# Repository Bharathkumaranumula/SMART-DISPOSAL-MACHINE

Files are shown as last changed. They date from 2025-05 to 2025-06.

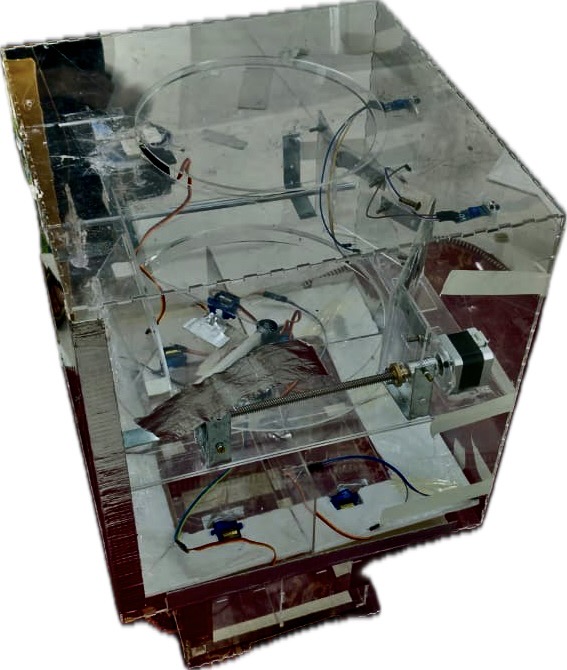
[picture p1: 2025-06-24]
sdm2.jpeg

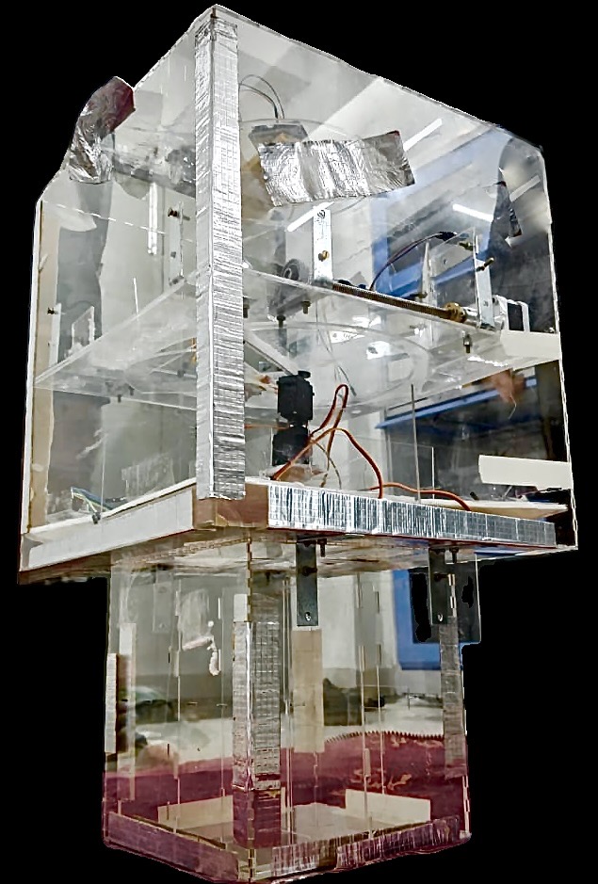
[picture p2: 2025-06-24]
Subject.jpeg

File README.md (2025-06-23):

♻️ Smart Disposal Machine - Green Guardian

Welcome to the repository of Green Guardian, a Smart Disposal Machine built to modernize and automate waste management. Designed with a combination of AI, IoT, and mechanical engineering tools this system aims to reduce human intervention, improve hygiene, and enable intelligent waste segregation.

🚀 Project Overview

The Smart Disposal Machine (SDM) is an innovative solution for waste handling that automatically:

-->Detects waste using a USB camera

-->Classifies it using AI (Gemini 1.5)

-->Compresses it with a lead screw mechanism.

-->Sorts it into the appropriate category (biodegradable, recyclable, or non-recyclable).

-->Monitors fill levels and notifies users in real-time via a web dashboard.

It is ideal for use in schools, campuses, offices, and smart cities, offering contactless interaction, increased efficiency, and scalable infrastructure for sustainable waste management.

🧠 Key Features

✅ AI-Powered Waste Classification: Utilizes Google Gemini 1.5 to categorize waste into proper compartments.

📆 Automated Compression : Reduces volume using a lead screw and NEMA17 stepper motor for extended storage capacity.

📡 IoT Monitoring : Ultrasonic sensors track bin levels in real-time and update a web dashboard (Streamlit).

🧬 Hygienic Operation : Touchless lid operation with IR sensors and servos minimizes contamination risk.

🗌 Web Dashboard : Real-time status with color indicators and bin location mapping. Includes unique bin IDs and notification alerts.

🛠️ Technical Stack

Component&                                         Description

AI Model      -----------------                                 Gemini 1.5 (Google)

Microcontrollers      --------------------                         Raspberry Pi 4, Arduino Uno

Sensors          ----------------------                              Ultrasonic, IR Proximity

Motors           ----------------------                              SG90 Servo, MG995 Servo, NEMA17 Stepper

Mechanism           ---------------------                            Lead Screw Compression + Flap-based Redirection

Software             -------------------------                          Python, Streamlit Dashboard

Communication            -----------------------                      USB Camera, IoT-based Monitoring

🔮 Future Enhancements

-->Integration with smart city waste routing systems.

-->Detection of hazardous and electronic waste.

-->Full automation of waste pickup via robotics.

-->More efficient deep-learning classification models.

🤝 Contributions
We welcome contributions from developers, engineers, and researchers. Feel free to fork the repo, open issues, or submit pull requests!

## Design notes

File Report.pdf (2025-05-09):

# Smart Disposal Machine A Scientific Report on Automated Waste Compression and Segregation “GREEN GUARDIAN”

### Hostel ID- 84

### 4th February 2024

1

Technical Report | Smart Disposal Machine | IIT Guwahati

## Contents

1 Abstract | 4
2 Problem Understanding | 4
3 Mechanical Module | 5
4 Electrical Components | 7
5 Approach | 13
6 AI Model Performance Evaluation | 14
7 User Interface | 14
8 Future Scope | 16
9 Existing Smart Disposal Technologies and Comparison | 16
10 Conclusion | 17
11 References | 18

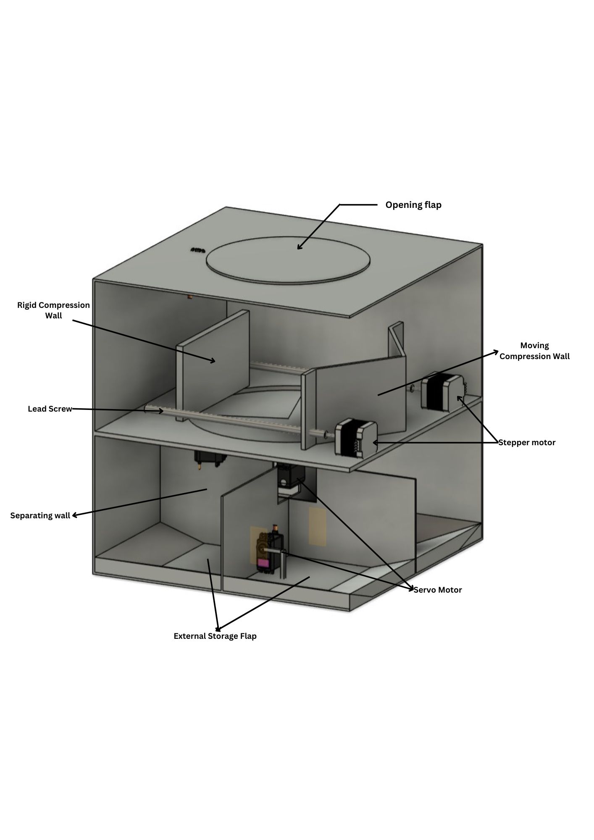
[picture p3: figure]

Figure 1:
Smart Disposal Machine

## 1 Abstract

The Smart Disposal Machine (SDM) is an advanced waste management system that incorporates AI-powered waste classification, real-time IoT monitoring, and automated mechanical segregation. This report describes the overall design of the system, focusing on the following key technologies: object detection using an SD Camera connected via USB, AI-based classification by -1.5 Pro refactor, and a lead screw-based compression mechanism to optimize waste storage and fill level monitoring via a streamlit dashboard. A mathematical model has been designed to estimate storage efficiency, waste compression, and mechanical performance. SDM considerably improves operational efficiency, sustainability, and hygiene in waste disposal at a much faster rate.

## 2 Problem Understanding

### 2.1 Challenges in Waste Management

- Inefficient Collection Schedules: Conventional dustbins require frequent manual

inspections to determine fill levels, leading to inefficiencies in waste collection.

- Overflowing Bins: High-traffic areas often experience overflowing containers,

creating unsanitary and unhygienic conditions.

- Hygiene Concerns: Maintenance staff are exposed to unsanitary conditions during

waste handling, posing health risks.

- Lack of Automation: Traditional systems lack real-time monitoring and automa-

tion, resulting in increased human intervention and operational costs.

### 2.2 Goals for the Smart Disposal Machine (SDM)

- Smart Monitoring and Notification:Use sensors to monitor fill levels in real-time

and notify personnel or automated systems when bins are full.

- Hygienic Operation: Minimize user and staff exposure to unsanitary conditions

during usage and maintenance.

- Extended Operational Time:Design the machine to extend the time between

trash retrievals using compaction or additional storage slots.

- Automation and IoT Integration:Provide remote monitoring capabilities through

a mobile app and improve automation to reduce human intervention.

- Waste Segregation:Automatically classify waste into categories such as biodegrad-

able, recyclable, and non-recyclable.

## 3 Mechanical Module

In this module in order to build the machine we have used acrylic sheets of thickness 3mm and 4mm

- Lid Mechanism: Infrared sensors are mounted onto the lid to detect motion which

would cause the lid to open or close that is facilitated by a servo motor imitating a hinge mechanism.

- Flap Mechanism: The bottom flap comprises two sections: a three-quarter circular

flap (A) and a quarter-circular flap (B) positioned beneath it.

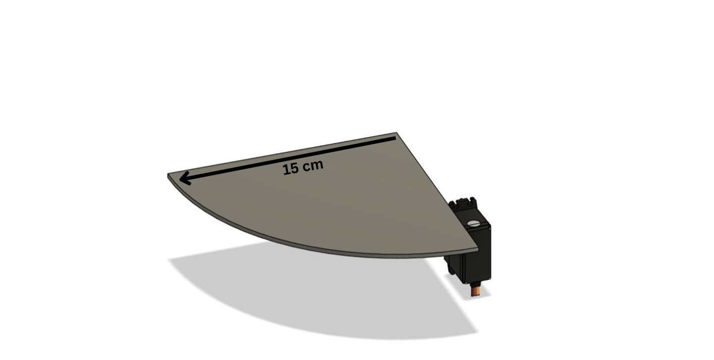
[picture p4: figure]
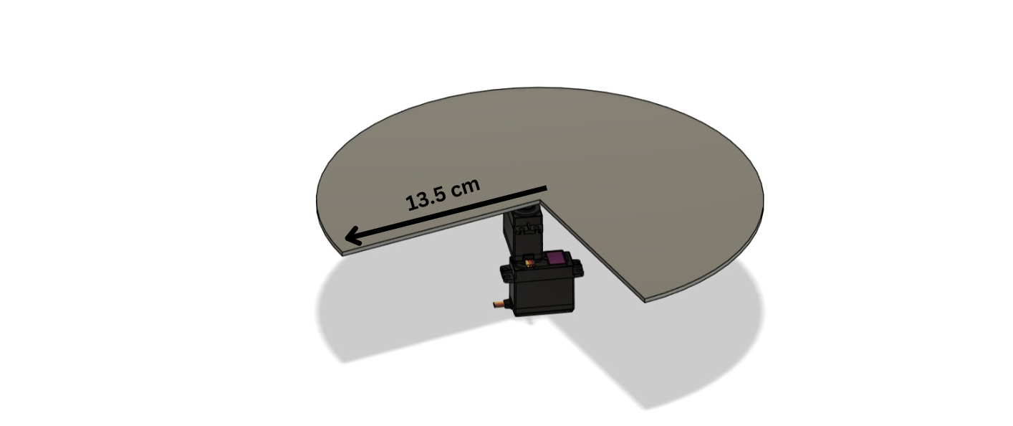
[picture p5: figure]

Flap A | Flap B

Prior to compression, these two sections align to form a complete circular flap. Post-compression, flap (B) slides beneath flap (A), revealing a cavity strategically aligned with the designated chamber for waste segregation.

- Compression Mechanism: We have used a lead screw mechanism to compress

the waste. A NEMA17 stepper motor which is controlled by a CNC shield that is connected from a Arduino Uno drives the lead screw forward when the waste is to be compressed and then moves it back to its original position. The speed and linear distance can be controlled by Arduino attached.

Linear Distance (mm) = Steps ×

Lead Screw Pitch (mm)
Steps per Revolution

To calculate the number of steps required:

Steps = Linear Distance (mm) ×

Steps per Revolution
Lead Screw Pitch (mm)

Lead Screw Dimensions- Length 20 cm and Diameter 8 mm

These formulas allow us to calculate the necessary movement of the piston to effectively compress the waste..

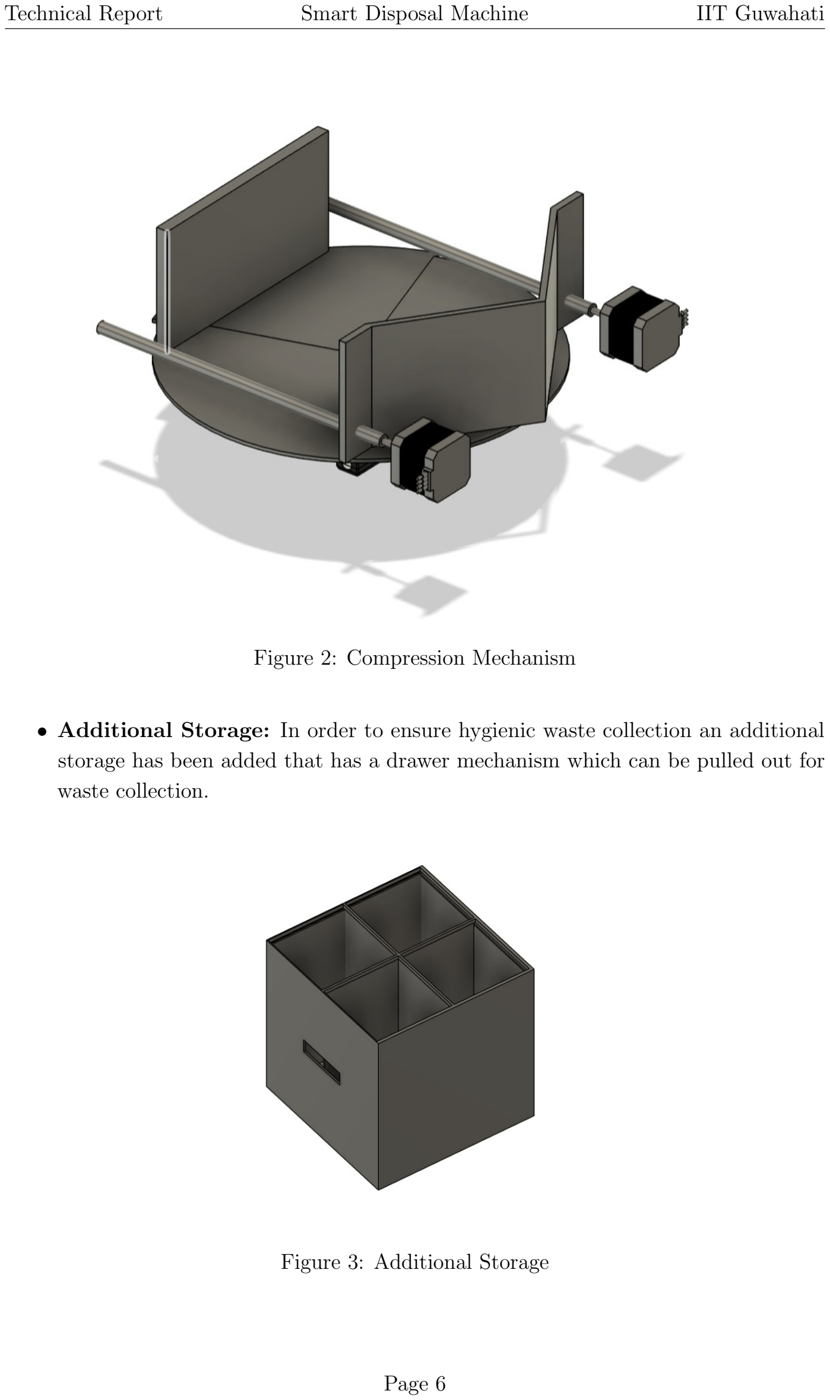
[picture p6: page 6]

Figure 2: Compression Mechanism

- Additional Storage: In order to ensure hygienic waste collection an additional

storage has been added that has a drawer mechanism which can be pulled out for waste collection.

Figure 3: Additional Storage

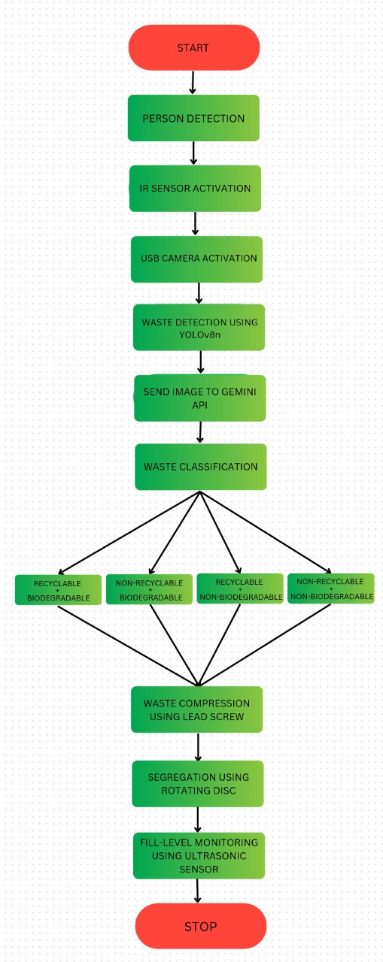
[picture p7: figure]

Figure 4: Flowchart for Mechanical System

## 4 Electrical Components

- Embedded Processing Unit (Raspberry Pi 4): The system employs a Rasp-

berry Pi (R-Pi) as the central processing unit, orchestrating overall system control. In order to execute this commands an Arduino is used.

Specifications:

– CPU: Quad-core Cortex-A72 (ARM v8) 64-bit @ 1.5GHz

– RAM: 2GB, 4GB, or 8GB LPDDR4

– GPU: VideoCore VI

– Ports: 2x USB 3.0, 2x USB 2.0, Gigabit Ethernet, HDMI (dual micro-HDMI)

– Wireless: Wi-Fi 802.11ac, Bluetooth 5.0

– Power: 5V/3A via USB-C

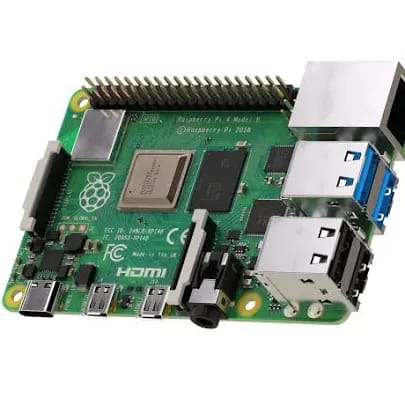
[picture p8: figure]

Figure 5: Raspberry Pi

- IR Proximity Sensor: Infrared (IR) proximity sensors offer a convenient and

hygienic way to automate lid operation. By emitting an invisible beam of infrared light and detecting its reflection, these sensors can determine when a hand or object approaches. This triggers a mechanism to open the lid without any physical contact, enhancing convenience and reducing the spread of germs. Similarly, the sensor can detect when the object moves away, prompting the lid to close automatically. Specifications:

– Detection Distance: 2-30 cm

– Detection angle: 35 deg

– Operating voltage: 3.6-5 V

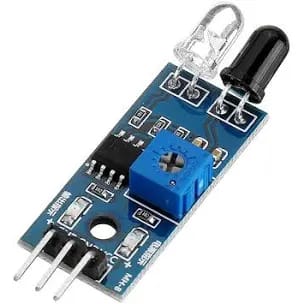
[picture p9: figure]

Figure 6: IR Sensor

- Camera Module: For enhanced waste segregation capabilities, a USB camera

has been integrated into the lid assembly. This camera captures images of waste deposited into the receptacle, enabling identification and classification through the utilization of Google’s Gemini 1.5 model.
Specifications:

– Resolution: 720p or 1080p

– Frame Rate: 30fps

– Interface: USB 2.0

– Focus: Fixed or Auto

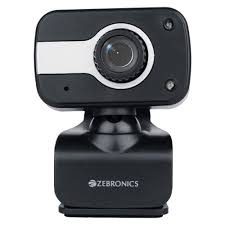
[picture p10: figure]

Figure 7: Camera

- Ultrasonic Sensors: Used to measure fill levels of storage compartments using

ultrasonic sound waves.
Specifications:

– Power Supply +5V DC

– Working Current 15mA

– Output Signal Electrical frequency signal

– Ranging Distance 2cms – 400 cms

– Resolution 0.3 cm

Ultrasonic Sensor calculates distance of nearby objects as follows:

Distance = Speed of Sound × Time Taken 2

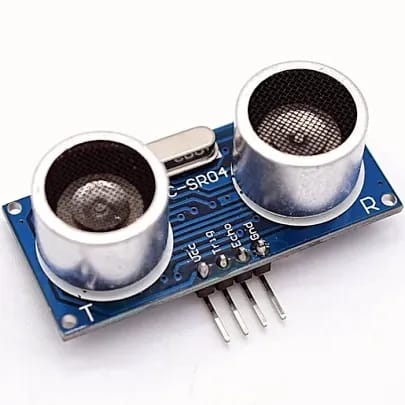
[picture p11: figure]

Figure 8: UltraSonic Sensor

- Servo Motor SG90: Specifications:

– Operating Voltage: 3 - 7.2V

– Rotation Degree: 180 deg

– Torque rating: 1.2-1.6 kg.cm

– Stall Torque @ 4.8V: 1.2 kg.cm

– Stall Torque @ 6.6V: 1.6 kg.cm

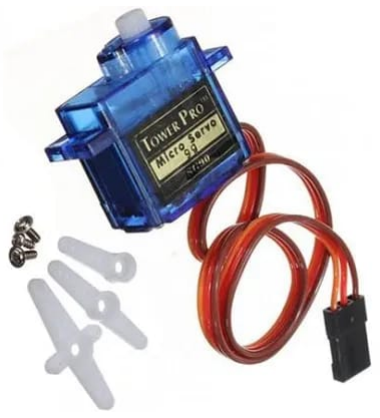
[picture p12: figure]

Figure 9: Servo Motor SG90

- Servo Motor MG995: Specifications:

– Operating Voltage: 4.8 - 7.2 V

– Rotation Degree: 180 deg

– Torque rating: 10-12 kg.cm

– Stall Torque @ 4.8V: 10 kg.cm

– Stall Torque @ 6.6V: 12 kg.cm

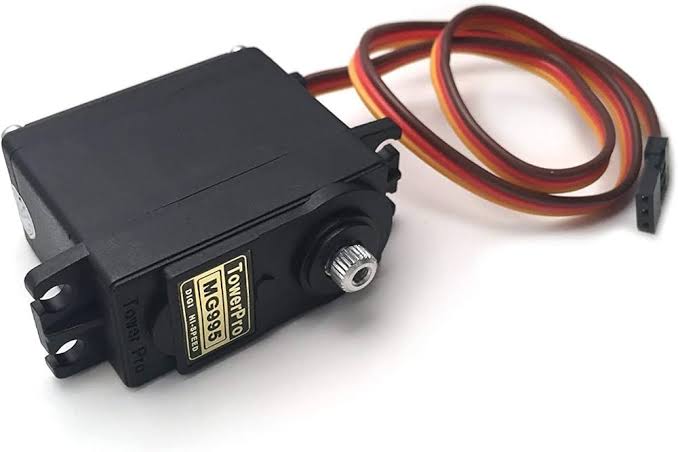
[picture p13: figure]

Figure 10: Servo Motor MG995

- CNC Shield: Specifications:

– Compatible with Arduino Uno

– Supports: 4 Stepper Drivers (A4988, DRV8825)

– 3-axis control, microstopping, end - stop pins

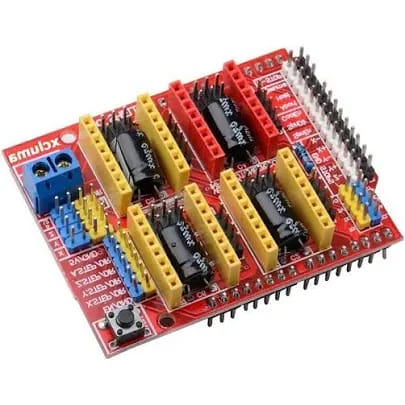
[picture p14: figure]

Figure 11: CNC SHIELD

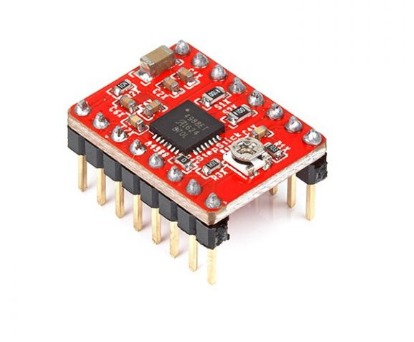
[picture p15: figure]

Figure 12: A4988 Stepper Driver

- Stepper Motor NEMA17: Specification:

– Shaft Type: D Type

– Step Angle: 1.8

– Holding Torque: 4.2kg-cm

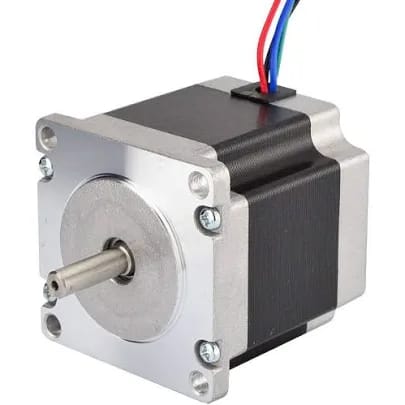
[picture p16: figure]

Figure 13: Servo Motor MG995

The working is shown in the flowchart below-

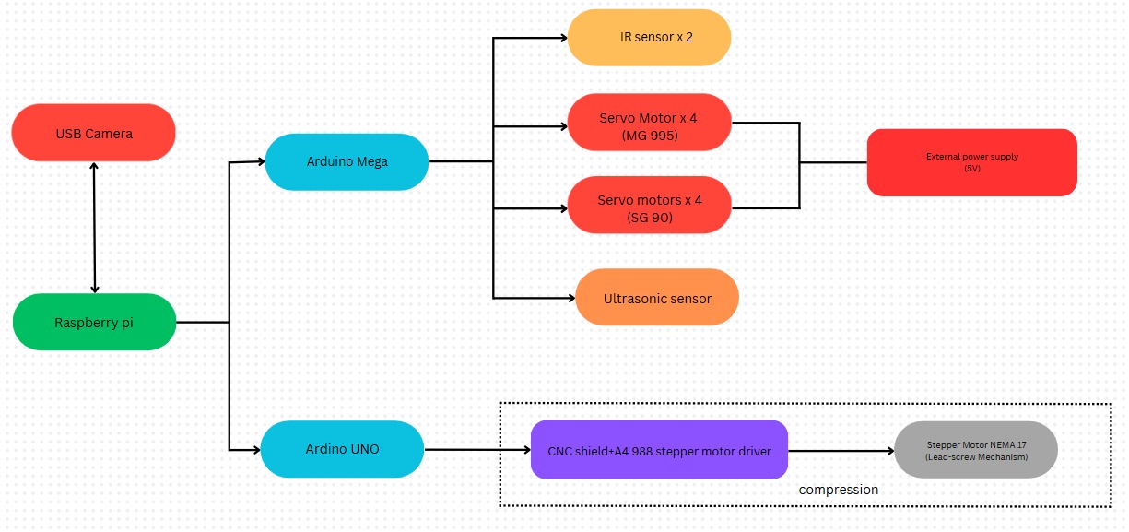
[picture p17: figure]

Figure 14: Flowchart for Electronic System

## 5 Approach

### 5.1 Fill-Level Monitoring

The fill level of the dustbin is monitored using an ultrasonic sensor, which captures readings over a specified period.These readings are used to calculated the percentage of the compartment that is filled. Later this is done for all the 4 compartments and the overall percentage fill is calculated.

### 5.2 Notification System

The notification system is designed to provide real-time alerts based on the fill levels of the dustbins. When the overall fill percentage of a bin exceeds 80%, a notification is triggered to prompt timely waste collection. Once the fill level drops below 80%, the notification is automatically removed. This system ensures efficient waste management by preventing overflow and optimizing collection schedules. Additionally, the dashboard visually highlights bins that require attention, enabling swift decision-making.To enhance monitoring, the bin includes LED indicators that display the bin’s status as empty, half-full, or full.

### 5.3 Waste segregation

To enable effective segregation of waste for disposal, the SDM has four compartments for segregation, which are divided on the basis of biodegradability and recyclability. The Gemini 1.5 system uses a USB camera mounted on the lid, which is used to recognize and sort items based on the above factors. After sorting, the system computes which lid to open, thus ensuring that the waste is loaded into the correct compartment. Additionally, a built-in compression unit compresses the waste before segregation, thus increasing the disposal volume before the bags are full.

### 5.4 Hygiene Operations

The dustbin system is designed with user convenience and hygiene in mind. It features a contactless disposal mechanism i.ea motion sensor-based opening, to minimize direct contact and enhance cleanliness. The surfaces are made easy to clean, and the waste compartments are detachable, allowing for effortless emptying and maintenance.

## 6 AI Model Performance Evaluation

A comparative analysis was conducted to evaluate different AI models for waste classification. The following table summarizes their performance metrics.

Model | Accuracy(%) | Inference time (sec) | Feasibility
DETR(deta-swin-large) | 50-60 | 1.2 | Computational intensive
YOLOv8n | 40-50 | 0.02 | Fast but less accurate
Google cloud vision API | 75-85 | 1-3 | Cloud dependent
Gemini 1.5 | 85-95 | 1-3 | Optimized for real-time deployment

Table 1: Comparison of Models

## 7 User Interface

In order to achieve real time monitoring the SDM is equipped with website url. Features of the site include:

- All the dustbins are further displayed on the map so as to provide more data

regarding dustbins in close vicinity that requires/would require waste collection simultaneously so that the process is done efficiently.

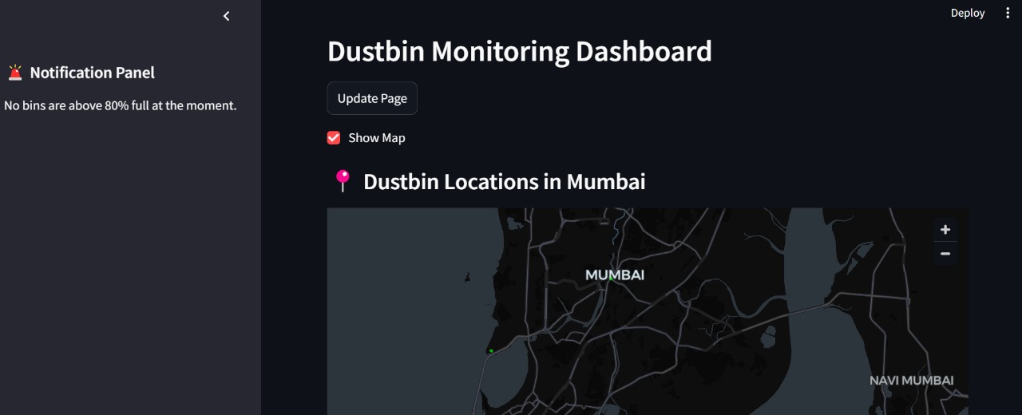
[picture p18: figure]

Figure 15

- Each dustbin is given a unique identification code which is displayed on the website.

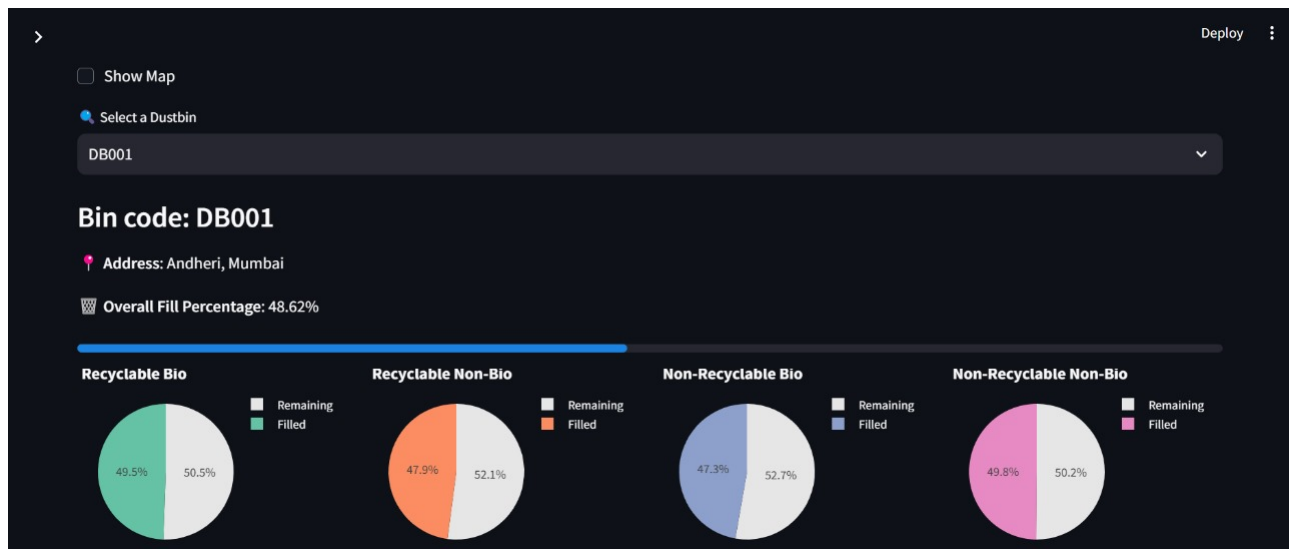
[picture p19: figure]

Figure 16

‘

- The website displays overall as well as individual percentage of waste filled in each

compartment.

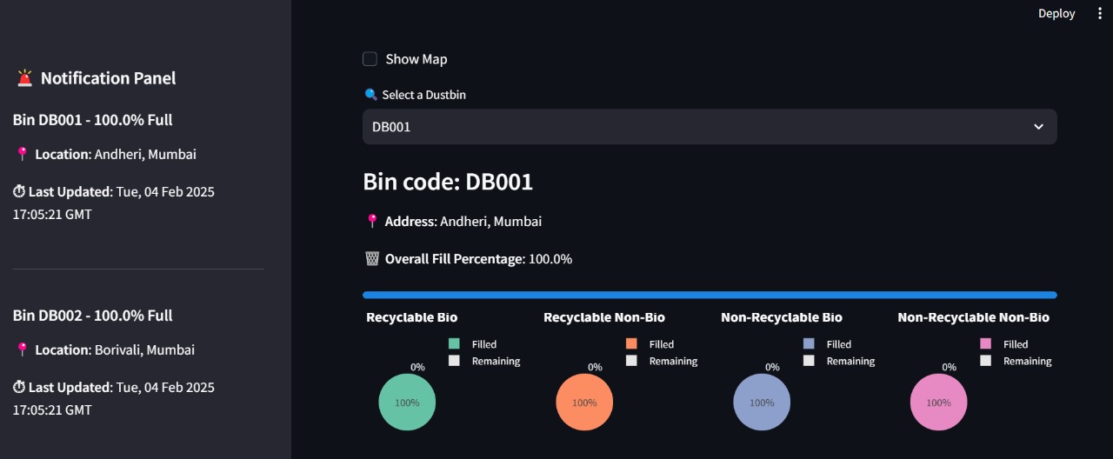
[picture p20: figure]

Figure 17

- The website also employs a colour scheme to indicate different levels of waste filled

in the dustbin. Green is for low or no waste filled, yellow for moderate and red indicates that more than 80 of the dustbin has been filled.

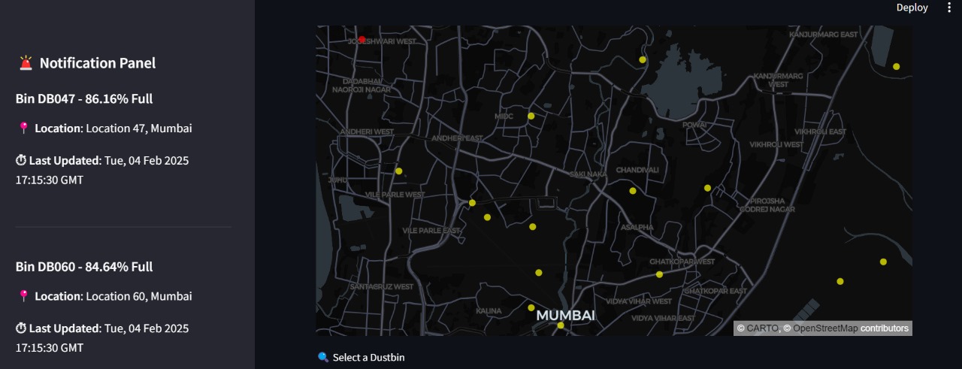
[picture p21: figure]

Figure 18

- A notification panel is also added to make it user friendly

## 8 Future Scope

- The sustainable disposal system can be scaled to diverse settings like office buildings,

factories, hospitals, airports, schools, fairs etc.

- Advanced machine learning models can be integrated for improved classification.
- The project can be further developed so as to fully automate waste collection and

disposal.

- Expanding detection capabilities for hazardous and electronic waste.
- The disposal system can be further integrated with smart city initiatives for sustain-

able living.

- The extendable storage can be automated so as to open up as soon as the waste

reaches the critical amount.

## 9 Existing Smart Disposal Technologies and Compar-

## ison

Several smart waste disposal technologies currently exist, utilizing various automation and monitoring features. Below is a comparison of existing systems and how our Smart Disposal Machine (SDM) surpasses them.
Our SDM improves upon existing solutions by incorporating AI-driven automation, real-time monitoring, optimized storage, and enhanced hygiene measures. This ensures better waste management, cost efficiency, and sustainability.

Feature | Existing Technologies | Our SDM
Fill-Level Monitoring | Uses ultrasonic sensors but lacks real-time IoT alerts | Utilizes ultrasonic and infrared sensors with IoT integration for real-time updates
Waste Segregation | Basic segregation using weight-based classification | AI-based segregation using Gemini-1.5 Pro Refractor for precise categorization
Compression Mechanism | Limited or no compression, leading to frequent emptying | Lead screw-based compression to optimize storage capacity
IoT and Automation | Some systems provide IoT fea-tures but with limited remote access | Full remote monitoring and control via a mobile app
Hygiene | Manual handling required in most existing solutions | Contactless operation
Cost | High initial costs with limited automation | Cost-effective with enhanced automation and smart analyt-ics

Table 2: Comparison of Existing Technologies vs. Our Smart Disposal Machine

## 10 Conclusion

The Smart Disposal Machine (SDM) is a revolutionary waste management technology that integrates AI-based classification, automatic sorting, and real-time IoT monitoring. Utilizing the application of Gemini-1.5 Pro for high-accuracy waste classification, the SDM provides efficient sorting, thereby ensuring maximum recycling potential and minimizing contamination across various waste streams.

The innovative design of the SDM features lead screw-based compression technology, which optimizes storage capacity and facilitates more effective space utilization. This feature has the potential to decrease waste collection frequency, resulting in reduced transportation costs and a reduced environmental impact.

Integration with IoT enables real-time waste tracking and alerts, facilitating valuable insights for proactive management and informed decision-making. By resolving core challenges inherent in current waste management systems, the SDM paves the way for more intelligent and sustainable waste management strategies for more urbanized cities.

## 11 References

- Isaac Onimisi Yusuf, Folashade Ariba, John Onyemenam, B. Adebanji, Banji

Adedayo, Adedotun Ijagbemi, Ibiloye Olaoluwa Samuel. (2024). A Smart and Automated Waste Management System. In 2024 International Conference on Science, Engineering and Business for Driving Sustainable Development Goals (SEB4SDG). https://www.semanticscholar.org/paper/c48da8e0e660eb7bb1d22550d2bf4ae3f8df3dd5

- @articlecarion2020detr, title=End-to-End Object Detection with Transformers, au-

thor=Carion, Nicolas and Massa, Francisco and Synnaeve, Gabriel and Usunier, Nicolas and Kirillov, Alexander and Zagoruyko, Sergey, year=2020, journal=arXiv preprint arXiv:2005.12872, url=https://arxiv.org/abs/2005.12872

- @miscjocher2023yolov5, title=YOLO by Ultralytics, author=Jocher, Glenn and

Chaurasia, Ayush and Qiu, Jirka and Stoken, Alexey, year=2023, note=Accessed: 2025-02-04, url=https://github.com/ultralytics/yolov5

- @manualgooglecloudvision, title=Cloud Vision API Documentation, author=Google

Cloud, note=Accessed: 2025-02-04, url=https://cloud.google.com/vision

- @miscgoogle2024gemini, title=Our next-generation model: Gemini 1.5, author=Google

DeepMind, year=2024, note=Accessed: 2025-02-04, url=https://blog.google/technology/ai/googlegemini-next-generation-model-february-2024/

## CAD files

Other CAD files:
CAD Design.f3z

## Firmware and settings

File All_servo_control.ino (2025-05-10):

#include <Wire.h>
#include <Adafruit_PWMServoDriver.h>
#include <string.h>

#define TRIG 2 // Ultrasonic sensor trigger pin
#define ECHO 3 // Ultrasonic sensor echo pin (PWM)
#define SERVO_FREQ 60 // PCA9685 PWM frequency for servos

Adafruit_PWMServoDriver pca = Adafruit_PWMServoDriver(0x40);

#define SERVO_BR 0   // Servo for Biodegradable & Recyclable waste bin
#define SERVO_BNR 1  // Servo for Biodegradable & Non-Recyclable waste bin
#define SERVO_NBR 2  // Servo for Non-Biodegradable & Recyclable waste bin
#define SERVO_NBNR 3 // Servo for Non-Biodegradable & Non-Recyclable waste bin
#define SERVO_LOW 4  // Lower servo in sorting mechanism
#define SERVO_UP 5   // Upper servo in sorting mechanism
#define SERVO_MID_FLAP 6 // Middle flap servo for waste direction
#define SERVO_LID 7  // Servo for Lid

#define PROXIMITY_OPEN 22  // To open main Lid
#define PROXIMITY_CLOSE 23 // To close main Lid

long updated_sensor_values[4] = {0, 0, 0, 0};

void setup() {
    Serial.begin(9600);
    while (!Serial) {}
    Serial.println("ARDUINO2");

    // Initialize PCA9685
    pca.begin();
    pca.setPWMFreq(SERVO_FREQ);
    
    pinMode(TRIG, OUTPUT);
    pinMode(ECHO, INPUT);
    pinMode(PROXIMITY_OPEN, INPUT);
    pinMode(PROXIMITY_CLOSE, INPUT);
    
    setServoPosition(SERVO_LOW, 0);
    setServoPosition(SERVO_UP, 0);
    setServoPosition(SERVO_MID_FLAP, 0);
    setServoPosition(SERVO_BR, 0);
    setServoPosition(SERVO_BNR, 0);
    setServoPosition(SERVO_NBR, 0);
    setServoPosition(SERVO_NBNR, 180);
    setServoPosition(SERVO_LID, 0);
}

void setServoPosition(int servo, int angle) {
    int pulse = map(angle, 0, 180, 150, 600); // Convert angle to PWM pulse width
    pca.setPWM(servo, 0, pulse);
}

void update_distance(int n) {
    delay(2000);
    digitalWrite(TRIG, LOW);
    delayMicroseconds(2);
    digitalWrite(TRIG, HIGH);
    delayMicroseconds(10);
    digitalWrite(TRIG, LOW);
    long duration = pulseIn(ECHO, HIGH);
    long distance = duration * 0.034 / 2;
    updated_sensor_values[n] = distance;
}

void disk_reset() {
    setServoPosition(SERVO_LOW, 0);
    setServoPosition(SERVO_UP, 0);
}

void bio_ren() {
    setServoPosition(SERVO_UP, 45);
    delay(1000);
    setServoPosition(SERVO_LOW, 0);
    delay(1000);
    setServoPosition(SERVO_MID_FLAP, 90);
    delay(3000);
    setServoPosition(SERVO_MID_FLAP, 0);
    delay(1000);
}

void bio_nonren() {
    setServoPosition(SERVO_UP, 170);
    delay(1000);
    setServoPosition(SERVO_LOW, 0);
    delay(1000);
    setServoPosition(SERVO_MID_FLAP, 90);
    delay(3000);
    setServoPosition(SERVO_MID_FLAP, 0);
    delay(1000);
}

void nonbio_ren() {
    setServoPosition(SERVO_UP, 170);
    delay(1000);
    setServoPosition(SERVO_LOW, 90);
    delay(1000);
    setServoPosition(SERVO_MID_FLAP, 90);
    delay(3000);
    setServoPosition(SERVO_MID_FLAP, 0);
    delay(1000);
}

void nonbio_nonren() {
    setServoPosition(SERVO_UP, 135);
    delay(1000);
    setServoPosition(SERVO_LOW, 180);
    delay(1000);
    setServoPosition(SERVO_MID_FLAP, 90);
    delay(3000);
    setServoPosition(SERVO_MID_FLAP, 0);
    delay(1000);
}

void flush_trash_to_external_bin() {
    setServoPosition(SERVO_BR, 90);
    setServoPosition(SERVO_BNR, 90);
    setServoPosition(SERVO_NBR, 80);
    setServoPosition(SERVO_NBNR, 180);
    delay(4000);
    setServoPosition(SERVO_BR, 0);
    setServoPosition(SERVO_BNR, 0);
    setServoPosition(SERVO_NBR, 0);
    setServoPosition(SERVO_NBNR, 0);
}

void close_lid() {
    setServoPosition(SERVO_LID, 0);
    delay(1000);
}

void open_lid() {
    setServoPosition(SERVO_LID, 90);
    delay(1000);
}

void loop()
{
  // Check for serial commands
  if (Serial.available() > 0)
  {
    String message = Serial.readStringUntil('\n');
    message.trim(); // Remove whitespace

    // Process different commands
    if (message.equals("BR"))
    {
      bio_ren();
      update_distance(0);
      disk_reset();
    }
    else if (message.equals("BNR"))
    {
      bio_nonren();
      update_distance(1);
      disk_reset();
    }
    else if (message.equals("NBR"))
    {
      nonbio_ren();
      update_distance(2);
      disk_reset();
    }
    else if (message.equals("NBNR"))
    {
      nonbio_nonren();
      update_distance(3);
      disk_reset();
    }
    else if (message.equals("GETD")) // Request bin levels
    {
      // Send all sensor values as comma-separated string
      Serial.print(updated_sensor_values[0]);
      Serial.print(",");
      Serial.print(updated_sensor_values[1]);
      Serial.print(",");
      Serial.print(updated_sensor_values[2]);
      Serial.print(",");
      Serial.println(updated_sensor_values[3]);
    }
    else if (message.equals("FLUSH")) // Empty all bins
    {
      flush_trash_to_external_bin();
    }
    else if (message.equals("RESTART"))
    {
      while (true)
      {
        if ((digitalRead(PROXIMITY_OPEN) == HIGH) && (digitalRead(PROXIMITY_CLOSE) == LOW))
        {
          open_lid();
        }
        else if ((digitalRead(PROXIMITY_CLOSE) == HIGH) && (digitalRead(PROXIMITY_OPEN) == LOW))
        {
          close_lid();
          break;
        }
        delay(1000);}
        }
}
}

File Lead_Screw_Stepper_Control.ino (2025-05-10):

// Pin definitions for CNC shield (X-axis)
#define DIR_PIN 5  // Direction pin
#define STEP_PIN 2 // Step pin
#define EN_PIN 8   // Enable pin (optional)
// Motor settings
#define STEPS_PER_REV 650                              // Steps per revolution for the stepper motor (change if needed)
#define DEGREE_TO_ROTATIONS(degrees) ((degrees) / 360) // Convert degrees to full rotations
#define STEP_DELAY_FAST 200                            // Step delay for fast forward motion (adjust for speed)
#define STEP_DELAY_SLOW 100                            // Step delay for slow return motion (adjust for speed)




void setup()
{
  // Set pins as outputs
  pinMode(DIR_PIN, OUTPUT);
  pinMode(STEP_PIN, OUTPUT);
  pinMode(EN_PIN, OUTPUT);

  // Enable the motor driver (LOW to enable, HIGH to disable)
  digitalWrite(EN_PIN, LOW); // Enable motor

  // Start serial communication for debugging
  Serial.begin(9600);
  //Serial.println("ARDUINO1"); // Send handshake signal
  Serial.println("Stepper Motor Ready. Send 'run' to start.");
}

void loop()
{
  if (Serial.available() > 0)
  {
    String command = Serial.readStringUntil('\n');

    if(command=="HANDSHAKE")
    {
      Serial.println("ARDUINO1");
    }

    // If the command is "run", start the motor sequence
    if (command == "COMPRESS")
    {
      Serial.println("Command received: Running the motor...");

      // Move piston forward for 3600 degrees (10 rotations)

      digitalWrite(DIR_PIN, LOW);                            // Set direction (HIGH for forward)
      moveMotor(DEGREE_TO_ROTATIONS(7200), STEP_DELAY_FAST); // Fast forward motion

      delay(1000); // Wait for 1 second before reversing direction

      // Move piston backward to return slowly

      digitalWrite(DIR_PIN, HIGH);                           // Set direction (LOW for reverse)
      moveMotor(DEGREE_TO_ROTATIONS(7200), STEP_DELAY_SLOW); // Slow return motion

      delay(1000);
    }
  } // Wait for 1 second before repeating
}

// Function to move the motor for the specified number of rotations
void moveMotor(int rotations, int stepDelay)
{
  int stepsToMove = rotations * STEPS_PER_REV; // Calculate total steps to move for the giverun n rotations

  // Rotate the motor by sending step pulses
  for (int i = 0; i < stepsToMove; i++)
  {
    digitalWrite(STEP_PIN, HIGH); // Step pulse HIGH
    delayMicroseconds(stepDelay); // Delay for controlling motor speed
    digitalWrite(STEP_PIN, LOW);  // Step pulse LOW
    delayMicroseconds(stepDelay); // Delay for controlling motor speed
  }
}

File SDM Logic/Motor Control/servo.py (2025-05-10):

import RPi.GPIO as GPIO
import time

SERVO_PIN = 17  # GPIO17 (Pin 11)
GPIO.setmode(GPIO.BCM)
GPIO.setup(SERVO_PIN, GPIO.OUT)

pwm = GPIO.PWM(SERVO_PIN, 50)  # 50Hz PWM signal
pwm.start(0)


def set_angle(angle):
    duty_cycle = (angle / 18) + 2
    pwm.ChangeDutyCycle(duty_cycle)
    time.sleep(0.5)

try:
    while True:
        for angle in range(0, 181, 30):  # Move from 0° to 180° in steps
            set_angle(angle)
            print(f"Moved to {angle}°")
        time.sleep(1)

        for angle in range(180, -1, -30):  # Move back from 180° to 0°
            set_angle(angle)
            print(f"Moved to {angle}°")
        time.sleep(1)

except KeyboardInterrupt:
    pwm.stop()
    GPIO.cleanup()
